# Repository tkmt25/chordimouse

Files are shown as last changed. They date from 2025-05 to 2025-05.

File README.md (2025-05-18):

# 概要
片手で操作できるBLEキーボード兼マウスを作るプロジェクトです。
マウスレイヤとキーボードレイヤを切り替えてこのデバイスだけで全ての操作が可能なことを目指します。

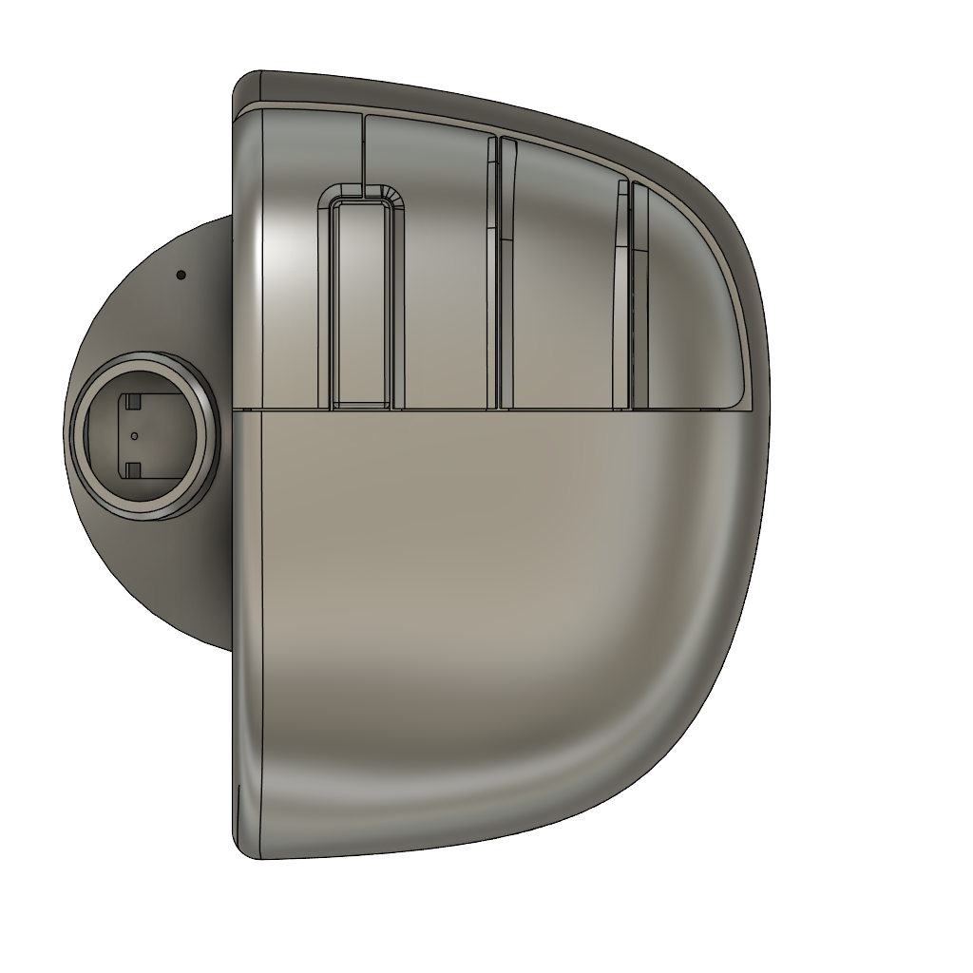
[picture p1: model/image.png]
イメージ


# 機能
- [ ] BLE接続先の切り替え(PC/スマホ等)
- [x] レイヤ切り替えでマウス/キーボード
- [x] 未使用時スリープ/使用時即復帰
- [x] キープロファイルの変更・保存
- [x] 各種設定の変更・保存

# 構成部品
| 型名 | 説明 | 個数 | 備考 |
| --- | --- | ---- | --- |
| SeeedStudio XIAO BLE nRF52840 | MCU | 1 | |
| D2F-01 | 和音入力等に使用するマイクロスイッチ | 5 | |
| RKJX21224001 | 和音入力等に使用するジョイスティック | 1 | https://tech.alpsalpine.com/j/products/detail/RKJX21224001/ |
| Capacitor(1uF) | スイッチのチャタリング防止用 | 6 | |
| DTP673450 | リチウムイオンポリマー電池 | 1 | |

# レイヤ構造
レイヤはジョイスティック押し込みで切り替え

ボタンは以下の通り
| ボタン名 | 略称 | 説明 |
| :--- | ---: | :--- |
| Button_1 | B1 | 人差し指のボタン |
| Button_2 | B2 | 中指のボタン |
| Button_3 | B3 | 薬指のボタン |
| Button_4 | B4 | 小指のボタン |
| MiddleButton_1 | M1 | 人差し指と中指の間のボタン |
| JoyStick_Up | JU | ジョイスティック上方向 |
| JoyStick_Down  | JD | ジョイスティック下方向 |
| JoyStick_Right | JR | ジョイスティック右方向 |
| JoyStick_Left  | JL | ジョイスティック左方向 |
| JoyStick_Press | JP | ジョイスティック押し込み |

## レイヤ1(マウス/デフォルト)
実装の都合上マウスレイヤのマッピングは変更不可。あとで変更可能にするかも

| ボタン | 挙動 | 変更可 |
| -----: | :--- | --- |
| JP | レイヤ切り替え | × |
| JU | マウス移動 | × |
| JD | マウス移動 | × |
| JR | マウス移動 | × |
| JL | マウス移動 | × |
| B1 | 左クリック | × |
| B2 | 右クリック | × |
| B3 | 戻る | × |
| B4 | 進む | × |
| M1 | - | × |
|  M1-JU | マウスホイール上 | × |
|  M1-JD | マウスホイール下 | × |
|  M1-JR | マウスホイール右 | × |
|  M1-JL | マウスホイール左 | × |

## レイヤ2(キーボード)
| ボタン | 挙動 | 変更可 |
| ---: | --- | --- |
| JP | レイヤ切り替え | × |
| JU | Ctrl | ○ |
| JD | Shift | ○ |
| JR | Fn | ○ |
| JL | Alt | ○ |
| B1 | Z | ○ |
| B2 | C | ○ |
| B3 | V | ○ |
| B4 | S | ○ |
| MB1 | F | ○ |
| B1-B2 | A | ○ |
| B1-B3 | B | ○ |
| B1-B4 | D | ○ |
| B1-MB | N | ○ |
| B2-B3 | P | ○ |
| B2-B4 | E | ○ |
| B2-MB | G | ○ |
| B3-B4 | H | ○ |
| B3-MB | I | ○ |
| B4-MB | J | ○ |
| B1-B2-B3 | K | ○ |
| B1-B2-B4 | L | ○ |
| B1-B2-MB | M | ○ |
| B1-B3-B4 | O | ○ |
| B1-B3-MB | Q | ○ |
| B1-B4-MB | R | ○ |
| B2-B3-B4 | T | ○ |
| B2-B3-MB | U | ○ |
| B2-B4-MB | W | ○ |
| B3-B4-MB | X | ○ |
| B1-B2-B3-B4 | Y | ○ |
| B1-B2-B3-MB | - | ○ |
| B1-B2-B4-MB | - | ○ |
| B1-B3-B4-MB | - | ○ |
| B2-B3-B4-MB | - | ○ |
| B1-B2-B3-B4-MB | - | ○ |

## Fnキー同時押し
| ボタン | 挙動 | 変更可 |
| ---: | --- | --- |
| B1 | Enter | ○ |
| B2 | Space | ○ |
| B3 | Tab | ○ |
| B4 | BackSpace | ○ |
| MB1 | Han/Zen | ○ |
| B1-B2 | Del | ○ |
| B1-B3 | ( | ○ |
| B1-B4 | ) | ○ |
| B1-MB | < | ○ |
| B2-B3 | > | ○ |
| B2-B4 | \ | ○ |
| B2-MB | : | ○ |
| B3-B4 | ; | ○ |
| B3-MB | @ | ○ |
| B4-MB | ! | ○ |
| B1-B2-B3 | 0 | ○ |
| B1-B2-B4 | 1 | ○ |
| B1-B2-MB | 2 | ○ |
| B1-B3-B4 | 3 | ○ |
| B1-B3-MB | 4 | ○ |
| B1-B4-MB | 5 | ○ |
| B2-B3-B4 | 6 | ○ |
| B2-B3-MB | 7 | ○ |
| B2-B4-MB | 8 | ○ |
| B3-B4-MB | 9 | ○ |
| B1-B2-B3-B4 | - | ○ |
| B1-B2-B3-MB | - | ○ |
| B1-B2-B4-MB | - | ○ |
| B1-B3-B4-MB | - | ○ |
| B2-B3-B4-MB | - | ○ |
| B1-B2-B3-B4-MB | - | ○ |

# スリープ
未操作から60秒(変更可)でスリープモードへ移行。スリープ中もBLE接続は維持される。
ボタン押下、ジョイスティック操作で復帰する。

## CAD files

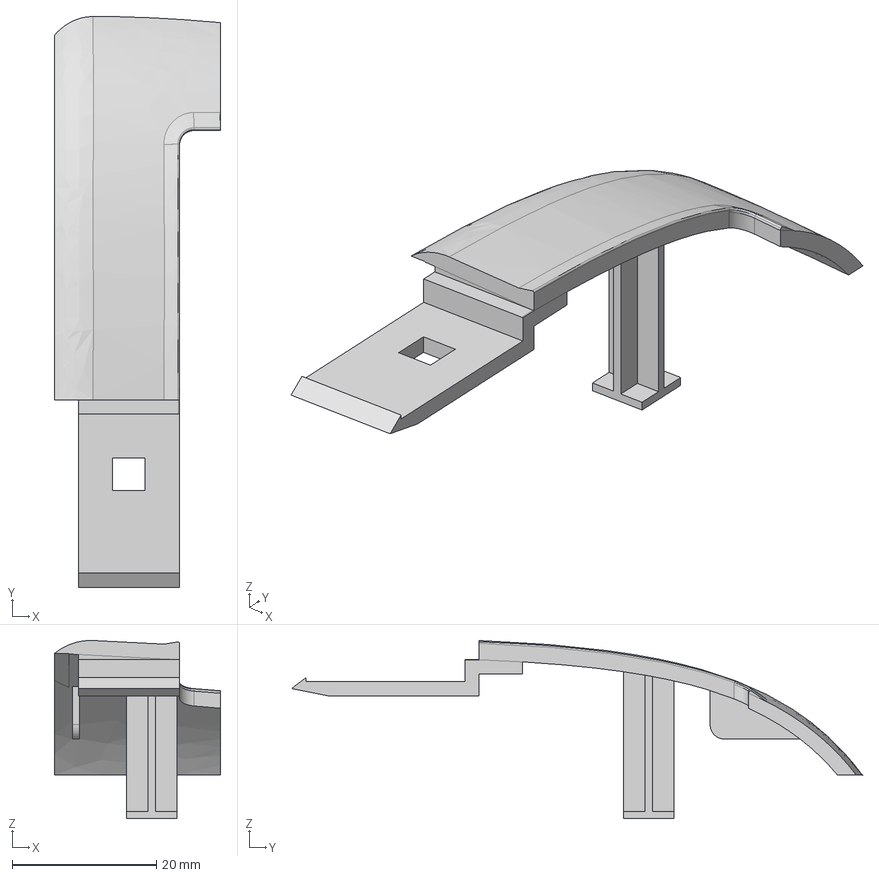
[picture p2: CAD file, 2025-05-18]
model/B1.step
23.0 x 79.1 x 24.7 mm

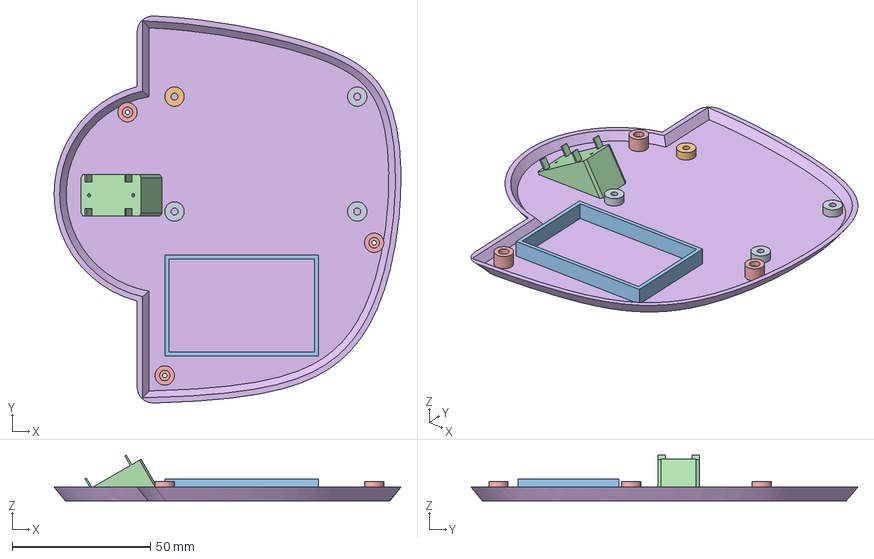
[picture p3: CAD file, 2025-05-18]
model/chasis.step
125.3 x 139.8 x 16.6 mm
ユニバ基板配置
バッテリボックス (1)
ジョイステ受け
接続用なじ穴

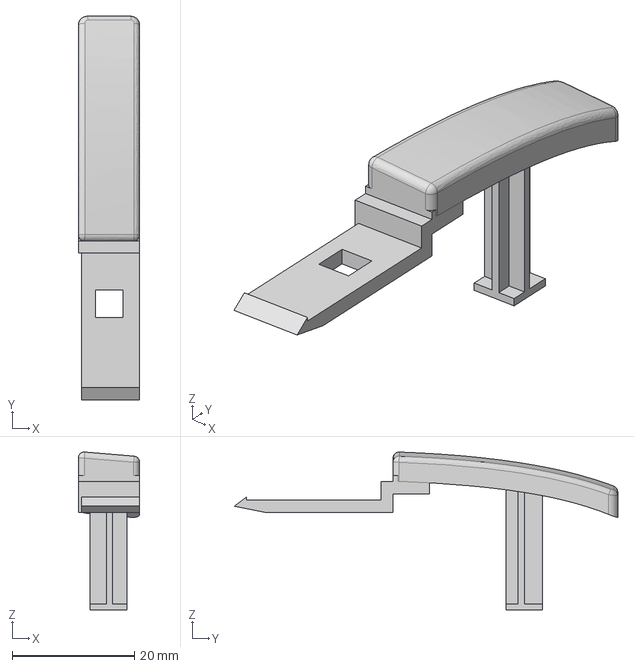
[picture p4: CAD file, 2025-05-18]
model/MB1.step
10.1 x 62.8 x 25.9 mm

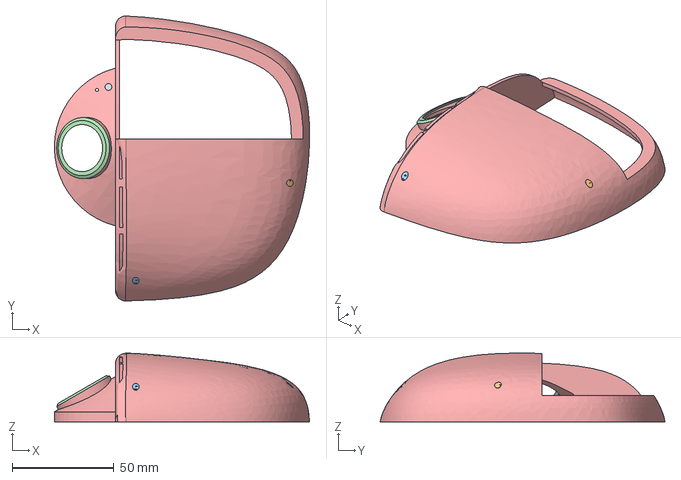
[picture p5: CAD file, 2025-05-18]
model/case.step
125.3 x 139.9 x 33.9 mm

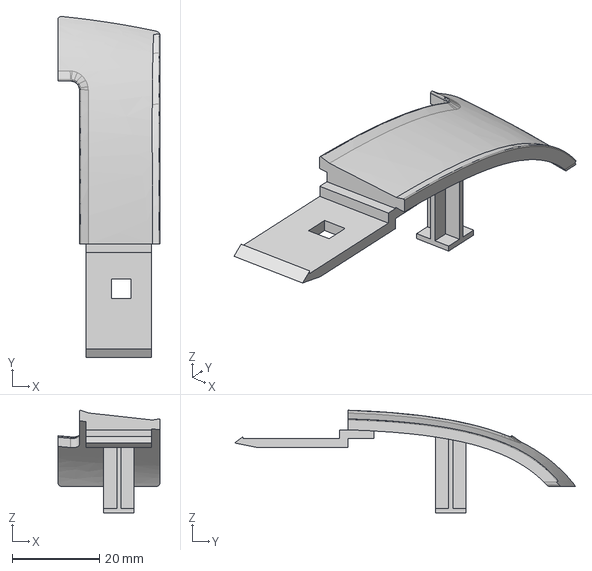
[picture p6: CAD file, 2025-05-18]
model/B2.step
23.4 x 78.1 x 23.5 mm

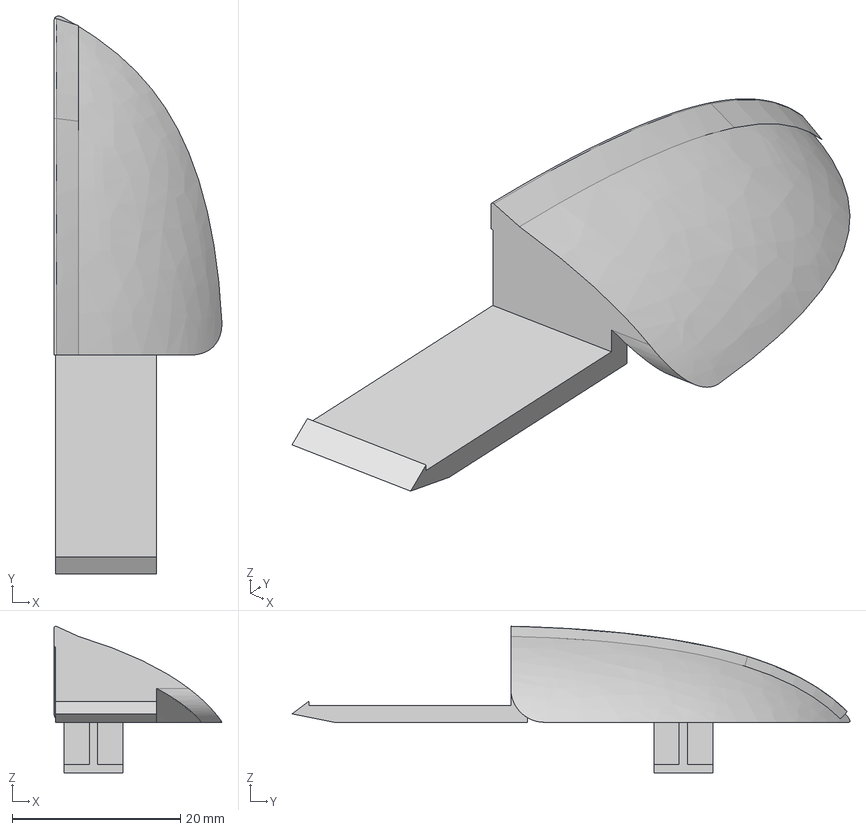
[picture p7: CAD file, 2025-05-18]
model/B4.step
19.9 x 66.3 x 17.4 mm

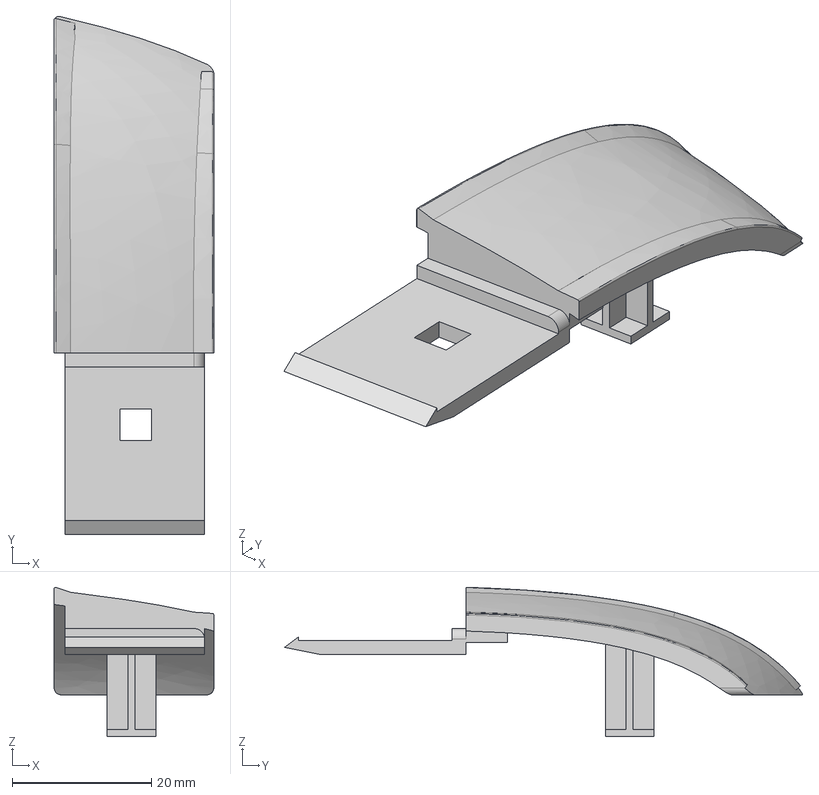
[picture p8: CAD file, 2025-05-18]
model/B3.step
22.9 x 74.3 x 21.4 mm

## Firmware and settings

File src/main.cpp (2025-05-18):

#include <Arduino.h>

#include <utility>
#include <utils/debug.h>
#include <alias.h>
#include <ble/ble_hid.h>
#include <ble/ble_config.h>

#include <config/config_manager.h>
#include <utils/internal_fs.h>

enum Mode {
  CONFIG,
  DEVICE
};

static constexpr module::Color LAYER_COLORS[2] = {
  module::Color::BLUE,
  module::Color::GREEN
};

static click_detector joystick_button;
static keyboard_layer keyboardLayer;
static key_profile profile;
static mouse_layer mouseLayer;
static int currentLayer = 0;

/**
 * @brief 設定を反映
 */
void applyConfig()
{
  // config
  {
    auto& cfg = config_manager::getGlobalConfig();
    mouseLayer.configure(cfg.getMouseNegativeGain(), cfg.getMickeyScale(), cfg.getMouseReportIntervalMs());
  }

  // keyprof
  {
    keyboardLayer.setKeyProfiles(config_manager::getKeyProfiles());
  }

  // calibration
  {
    auto& calib = config_manager::getCalibration();
    mouseLayer.cariblate(calib);
    keyboardLayer.cariblate(calib);
  }
}

/**
 * @brief 初期化処理
 */
void setup()
{
  debugInit();
  stopwatch_ms();

#if 0
  // InternalFSをクリア
  {
    if (InternalFS.begin()) {
      InternalFS.format();
    }
  }
#endif

  // 外部Flashは使わないので停止
  {
    stopwatch_ms();
    sleep_controller::enterSleepQSPIFlash();
  }
  

  // ピン初期設定
  button1::assign();
  button2::assign();
  button3::assign();
  button4::assign();
  middle_button1::assign();
  mode_sw::assign();
  joystick::assign();
  led_indicator::assign();

  // 未使用ピン
  pinMode(gpio::UNUSED_1, OUTPUT); 
  digitalWrite(gpio::UNUSED_1, LOW);
  pinMode(gpio::UNUSED_2, OUTPUT); 
  digitalWrite(gpio::UNUSED_2, LOW);

  // 設定値読み込み
  config_manager::init();
  applyConfig();

  // BLE初期化
  ble::init();
  ble::ble_hid::init();
  ble::ble_config::init();

#if 0
  Bluefruit.Periph.clearBonds();
#endif

  // セットアップ済み
  led_indicator::turnOnWith(LAYER_COLORS[currentLayer]);

  // スリープカウンタリセット
  sleep_controller::resetSleepCount();
}


/**
 * @brief メインループ
 */
void loop()
{
  static Mode mode = Mode::DEVICE;
  bool wasAction = false;
  stopwatch_ms();

  // モードトグル
  joystick_button.update();
  if (joystick_button.isLongPressed()) {
    joystick_button.reset();

    switch(mode) {
      case DEVICE:
      {
        mode = Mode::CONFIG;
        led_indicator::startBlink(module::Color::PURPLE, 500);
        ble::ble_hid::disconnect();
        break;
      }
        
      case CONFIG:
      {
        mode = Mode::DEVICE;
        led_indicator::stopBlink(); 
        ble::ble_config::disconnect();
        led_indicator::turnOnWith(LAYER_COLORS[currentLayer]);
        break;
      }
    }
  }

  // メイン処理
  switch(mode) {

    // 設定モード
    case Mode::CONFIG:
    {
      {
        if (!ble::ble_config::isConnected()) {
          DEBUG_PRINTF("start advertising ble config");

          ble::ble_config::setUpdateConfigCallback([](const config& cfg) {
            DEBUG_PRINTF("config updated by ble %f", cfg.getMickeyScale());
            config_manager::saveConfig(cfg);
            applyConfig();
          });
          ble::ble_config::setUpdateKeyProfCallback([](const key_profiles& profs) {
            DEBUG_PRINTF("updated key profiles ");
            config_manager::saveKeyProfiles(profs);
            applyConfig();
          });
          ble::ble_config::setDisconnectCallback([](){
            mode = Mode::DEVICE;
          });

          ble::ble_config::connect(config_manager::getGlobalConfig(), config_manager::getKeyProfiles(), 5000);
        }
      }
    }
    break;


    // デバイスモード
    case Mode::DEVICE:
    {
      // BLEアドバタイズ(完了まで待機)
      // TODO: ボタン切り替え未実装のためとりあえず固定
      //ble::begin(mode_sw::isPressed() ? 0 : 1);
      if (!ble::ble_hid::isConnected()){
        stopwatch_ms("ble connect");
        auto& cfg = config_manager::getGlobalConfig();
        led_indicator::startBlink(module::Color::BLUE, 500);
        bool connected = ble::ble_hid::connect(1, 5000, ble::ConnectionParam{
          .connectionIntervalMin = cfg.getConnectionIntervalMin(),
          .connectionIntervalMax = cfg.getConnectionIntervalMax(),
          .slaveLatency = 0,
          .timeout = 2000,
          .txPower = cfg.getTxPower()
        });

        if (connected) {
          DEBUG_PRINTF("connected hid!");
          led_indicator::stopBlink();
          led_indicator::turnOnWith(LAYER_COLORS[currentLayer]);

          {
            mouseLayer.configure(cfg.getMouseNegativeGain(), cfg.getMickeyScale(), cfg.getMouseReportIntervalMs());
          }

          wasAction = true;
        }
        
        goto FINALIZE;
      }

      // 入力処理
      switch (currentLayer)
      {
        case 0: // mouse layer
        {
          if (joystick_button.isClicked()) {
            currentLayer = 1;
            led_indicator::turnOnWith(LAYER_COLORS[currentLayer]);
            break;
          }
          wasAction = mouseLayer.action();
          break;
        }

        case 1: // keyboard layer
        {
          if (joystick_button.isClicked()) {
            currentLayer = 0;
            led_indicator::turnOnWith(LAYER_COLORS[currentLayer]);

            // 全てボタン離す
            // TODO: 無理やりやってるので後でコード整理
            ble::ble_hid::keyRelease();
            applyConfig(); // TODO: リセット処理は別にしたい

            break;
          }
          auto [chord, event] = keyboardLayer.scanChord(config_manager::getGlobalConfig().getChordScanTimeoutMs());
          wasAction = keyboardLayer.action(chord, event);
          break;
        }
      }
    }

    break;
  }

FINALIZE:

  // 操作ありならスリープカウントリセット
  if (wasAction || mode==Mode::CONFIG)
  {
    sleep_controller::resetSleepCount();
  }

  // スリープ処理
  if (sleep_controller::shouldEnterSleep(config_manager::getGlobalConfig().getLightSleepTimeoutMs()))
  {
    led_indicator::turnOff();
    led_indicator::stopBlink();
    
    // SystemONSleepでタイムアウトした場合はDeepSleepに移行
    auto wasTimeout = sleep_controller::enterLightSleep(config_manager::getGlobalConfig().getDeepSleepTimeoutMs());
    if (wasTimeout) {
      sleep_controller::enterDeepSleep();
      // ここからは復帰しない→setup()に戻る
    }

    // lightsleep通常復帰
    led_indicator::turnOnWith(LAYER_COLORS[currentLayer]);
    applyConfig();
    sleep_controller::resetSleepCount();
  }
  //delayMicroseconds(500);
  //yield();
}

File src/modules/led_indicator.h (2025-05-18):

#pragma once

#include <Arduino.h>


namespace module
{
    /**
     * @brief 色を表す列挙値
     */
    enum Color
    {
        RED = 0x04,
        GREEN = 0x02,
        BLUE = 0x01,
        PURPLE = RED | BLUE,
        YELLOW = RED | GREEN,
        CYAN = GREEN | BLUE,
        WHITE = RED | GREEN | BLUE,
    };


    /**
     * @brief LEDインジケータの制御クラス。アノードコモン
     * @tparam pinRed   赤のピン番号
     * @tparam pinGreen 緑のピン番号
     * @tparam pinBlue  青のピン番号
     */
    template <uint8_t pinRed, uint8_t pinGreen, uint8_t pinBlue>
    class led_indicator
    {
    public:
        led_indicator() = default;


        /**
         * @brief ピンをアサイン
         */
        constexpr static void assign()
        {
            pinMode(pinRed, OUTPUT);
            pinMode(pinGreen, OUTPUT);
            pinMode(pinBlue, OUTPUT);
        }


        /**
         * @brief 色を設定する
         * @param [in] color 色
         * 
         * @note 指定した色で点灯させるにはturnOnをコール
         */
        static inline void setColor(const Color color)
        {
            _color = color;
        }


        /**
         * @brief 点灯します
         * @note setColorで設定した色になります
         */
        constexpr static void turnOn()
        {
            // アノードコモンのため、LOWで点灯
            digitalWrite(pinRed,   !((_color & RED)   >> 2));
            digitalWrite(pinGreen, !((_color & GREEN) >> 1));
            digitalWrite(pinBlue,  !((_color & BLUE)  ));
        }


        /**
         * @brief 指定した色で点灯します
         * @param [in] color 色
         */
        constexpr static void turnOnWith(const Color color)
        {
            turnOff();
            setColor(color);
            turnOn();
        }


        /**
         * @brief 消灯します
         */
        constexpr static void turnOff()
        {
            digitalWrite(pinRed, HIGH);
            digitalWrite(pinGreen, HIGH);
            digitalWrite(pinBlue, HIGH);
        }


        constexpr static void startBlink(const Color color, const uint32_t intervalMs)
        {
            turnOff();
            setColor(color);
            startBlink(intervalMs);
        }

        /**
         * @brief 点滅を開始します
         * @param interval 点滅間隔(ms)
         * @note 色はsetRGBで設定した色になります
         */
        static inline void startBlink(const uint32_t intervalMs)
        {
            if (_isBlinking) {
                return ;
            }

            // タイマーカウント値を計算（31.25kHz で interval_ms 毎に割り込み）
            uint32_t ticks = 31250 * intervalMs / 1000;

            NRF_TIMER1->BITMODE = TIMER_BITMODE_BITMODE_32Bit;
            
            // -----------------------------
            // GPIOTE 設定（色ごとに設定）
            // 各ピンを「トグルするタスク」に割り当てる
            // -----------------------------

            if (_color & RED)
            {
                NRF_GPIOTE->CONFIG[GPIOTE_RED_CH] =
                    (GPIOTE_CONFIG_MODE_Task << GPIOTE_CONFIG_MODE_Pos) |
                    (g_ADigitalPinMap[pinRed] << GPIOTE_CONFIG_PSEL_Pos) |
                    (GPIOTE_CONFIG_POLARITY_Toggle << GPIOTE_CONFIG_POLARITY_Pos) |
                    (GPIOTE_CONFIG_OUTINIT_Low << GPIOTE_CONFIG_OUTINIT_Pos); // 初期値LOW
            }

            if (_color & GREEN)
            {
                NRF_GPIOTE->CONFIG[GPIOTE_GREEN_CH] =
                    (GPIOTE_CONFIG_MODE_Task << GPIOTE_CONFIG_MODE_Pos) |
                    (g_ADigitalPinMap[pinGreen] << GPIOTE_CONFIG_PSEL_Pos) |
                    (GPIOTE_CONFIG_POLARITY_Toggle << GPIOTE_CONFIG_POLARITY_Pos) |
                    (GPIOTE_CONFIG_OUTINIT_Low << GPIOTE_CONFIG_OUTINIT_Pos);
            }

            if (_color & BLUE)
            {
                NRF_GPIOTE->CONFIG[GPIOTE_BLUE_CH] =
                    (GPIOTE_CONFIG_MODE_Task << GPIOTE_CONFIG_MODE_Pos) |
                    (g_ADigitalPinMap[pinBlue] << GPIOTE_CONFIG_PSEL_Pos) |
                    (GPIOTE_CONFIG_POLARITY_Toggle << GPIOTE_CONFIG_POLARITY_Pos) |
                    (GPIOTE_CONFIG_OUTINIT_Low << GPIOTE_CONFIG_OUTINIT_Pos);
            }

            // -----------------------------
            // TIMER1 設定
            // -----------------------------

            NRF_TIMER1->MODE = TIMER_MODE_MODE_Timer << TIMER_MODE_MODE_Pos; // タイマーモード
            NRF_TIMER1->PRESCALER = 9;                                       // 16MHz / 2^9 = 31.25kHz
            NRF_TIMER1->BITMODE = TIMER_BITMODE_BITMODE_16Bit << TIMER_BITMODE_BITMODE_Pos;
            NRF_TIMER1->CC[0] = ticks;                                                                   // 指定間隔のカウント値設定
            NRF_TIMER1->SHORTS = TIMER_SHORTS_COMPARE0_CLEAR_Enabled << TIMER_SHORTS_COMPARE0_CLEAR_Pos; // 自動リセット
            NRF_TIMER1->TASKS_START = 1;                                                                 // タイマー開始

            // -----------------------------
            // PPI 設定：タイマーイベント → GPIOTE タスクを接続
            // -----------------------------

            if (_color & RED)
            {
                NRF_PPI->CH[PPI_RED_CH].EEP = (uint32_t)&NRF_TIMER1->EVENTS_COMPARE[0];        // イベント：タイマー0一致
                NRF_PPI->CH[PPI_RED_CH].TEP = (uint32_t)&NRF_GPIOTE->TASKS_OUT[GPIOTE_RED_CH]; // タスク：GPIOTEで出力トグル
                NRF_PPI->CHENSET = (1 << PPI_RED_CH);                                          // PPIチャネル有効化
            }

            if (_color & GREEN)
            {
                NRF_PPI->CH[PPI_GREEN_CH].EEP = (uint32_t)&NRF_TIMER1->EVENTS_COMPARE[0];
                NRF_PPI->CH[PPI_GREEN_CH].TEP = (uint32_t)&NRF_GPIOTE->TASKS_OUT[GPIOTE_GREEN_CH];
                NRF_PPI->CHENSET = (1 << PPI_GREEN_CH);
            }

            if (_color & BLUE)
            {
                NRF_PPI->CH[PPI_BLUE_CH].EEP = (uint32_t)&NRF_TIMER1->EVENTS_COMPARE[0];
                NRF_PPI->CH[PPI_BLUE_CH].TEP = (uint32_t)&NRF_GPIOTE->TASKS_OUT[GPIOTE_BLUE_CH];
                NRF_PPI->CHENSET = (1 << PPI_BLUE_CH);
            }

            _isBlinking = true;
        }

        
        /**
         * @brief 点滅を停止します
         */
        static inline void stopBlink()
        {
            if (!_isBlinking) {
                return ;
            }

            // タイマー停止＆リセット
            NRF_TIMER1->TASKS_STOP = 1;
            NRF_TIMER1->TASKS_CLEAR = 1;

            // GPIOTE設定解除 & LED OFF
            if (_color & RED)
            {
                NRF_PPI->CHENCLR = (1 << PPI_RED_CH);
                NRF_GPIOTE->CONFIG[GPIOTE_RED_CH] = 0;
                digitalWrite(pinRed, HIGH);
            }

            if (_color & GREEN)
            {
                NRF_PPI->CHENCLR = (1 << PPI_GREEN_CH);
                NRF_GPIOTE->CONFIG[GPIOTE_GREEN_CH] = 0;
                digitalWrite(pinGreen, HIGH);
            }

            if (_color & BLUE)
            {
                NRF_PPI->CHENCLR = (1 << PPI_BLUE_CH);
                NRF_GPIOTE->CONFIG[GPIOTE_BLUE_CH] = 0;
                digitalWrite(pinBlue, HIGH);
            }

            _isBlinking = false;
        }
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

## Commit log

2025-05-18 ページ追加
2025-05-18 page修正
2025-05-18 workflow修正
2025-05-18 廃止actionを修正
